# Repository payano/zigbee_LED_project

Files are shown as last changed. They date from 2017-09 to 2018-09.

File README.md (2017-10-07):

# zigbee_LED_project

Inspiration:
https://arduinodiy.wordpress.com/2012/05/02/using-mosfets-with-ttl-levels/

this aswell: https://github.com/karlp/Mrf24j40-arduino-library/

Potentiometer
BC547
IRF3205
LED-panel (aliexpress)
RGBW-led strips (aliexpress)

THIS TOO: https://electronics.stackexchange.com/questions/132000/stm32-series-microcontroller-calculations-of-timer-variables

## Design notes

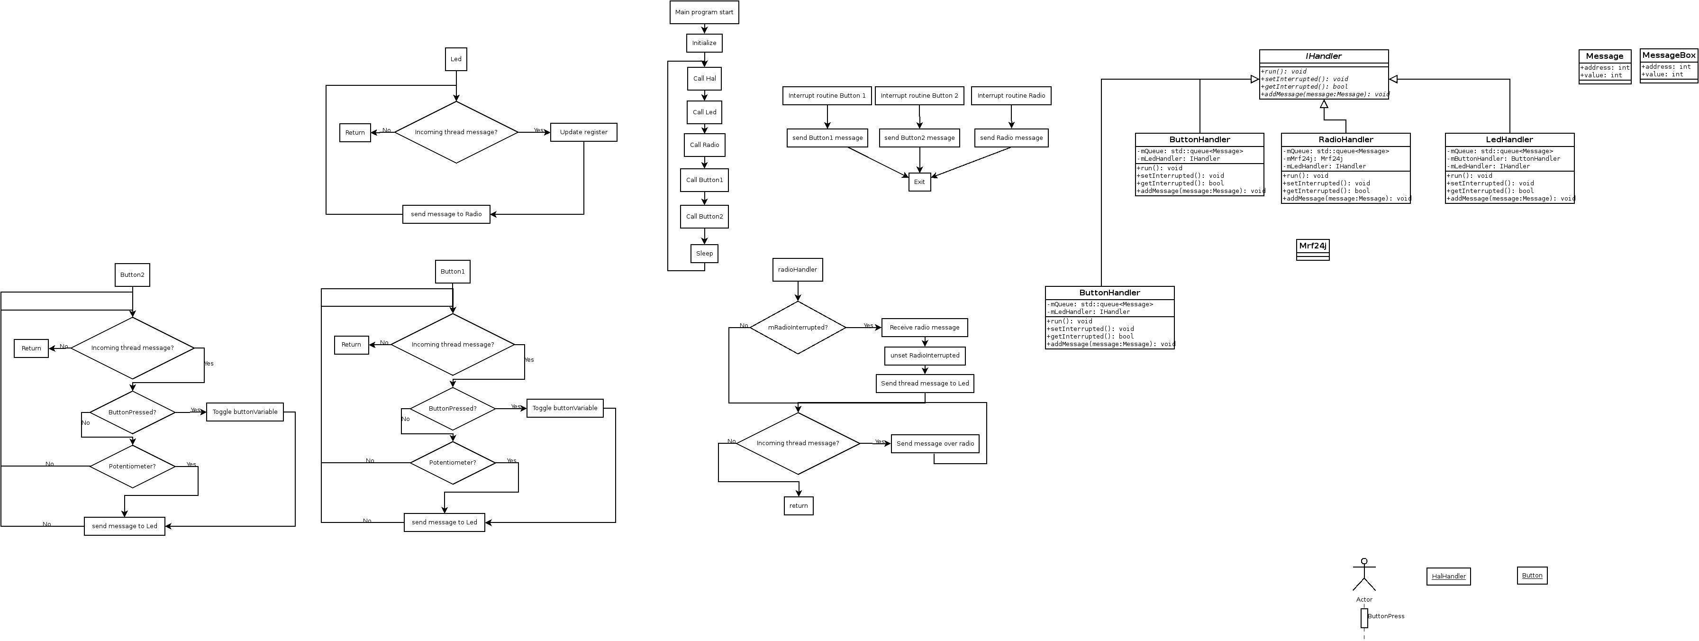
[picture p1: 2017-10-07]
flowchart.png

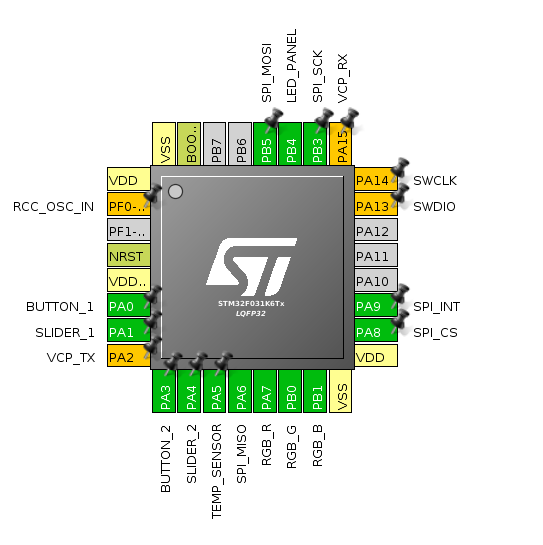
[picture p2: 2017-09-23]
stm32_layout.png

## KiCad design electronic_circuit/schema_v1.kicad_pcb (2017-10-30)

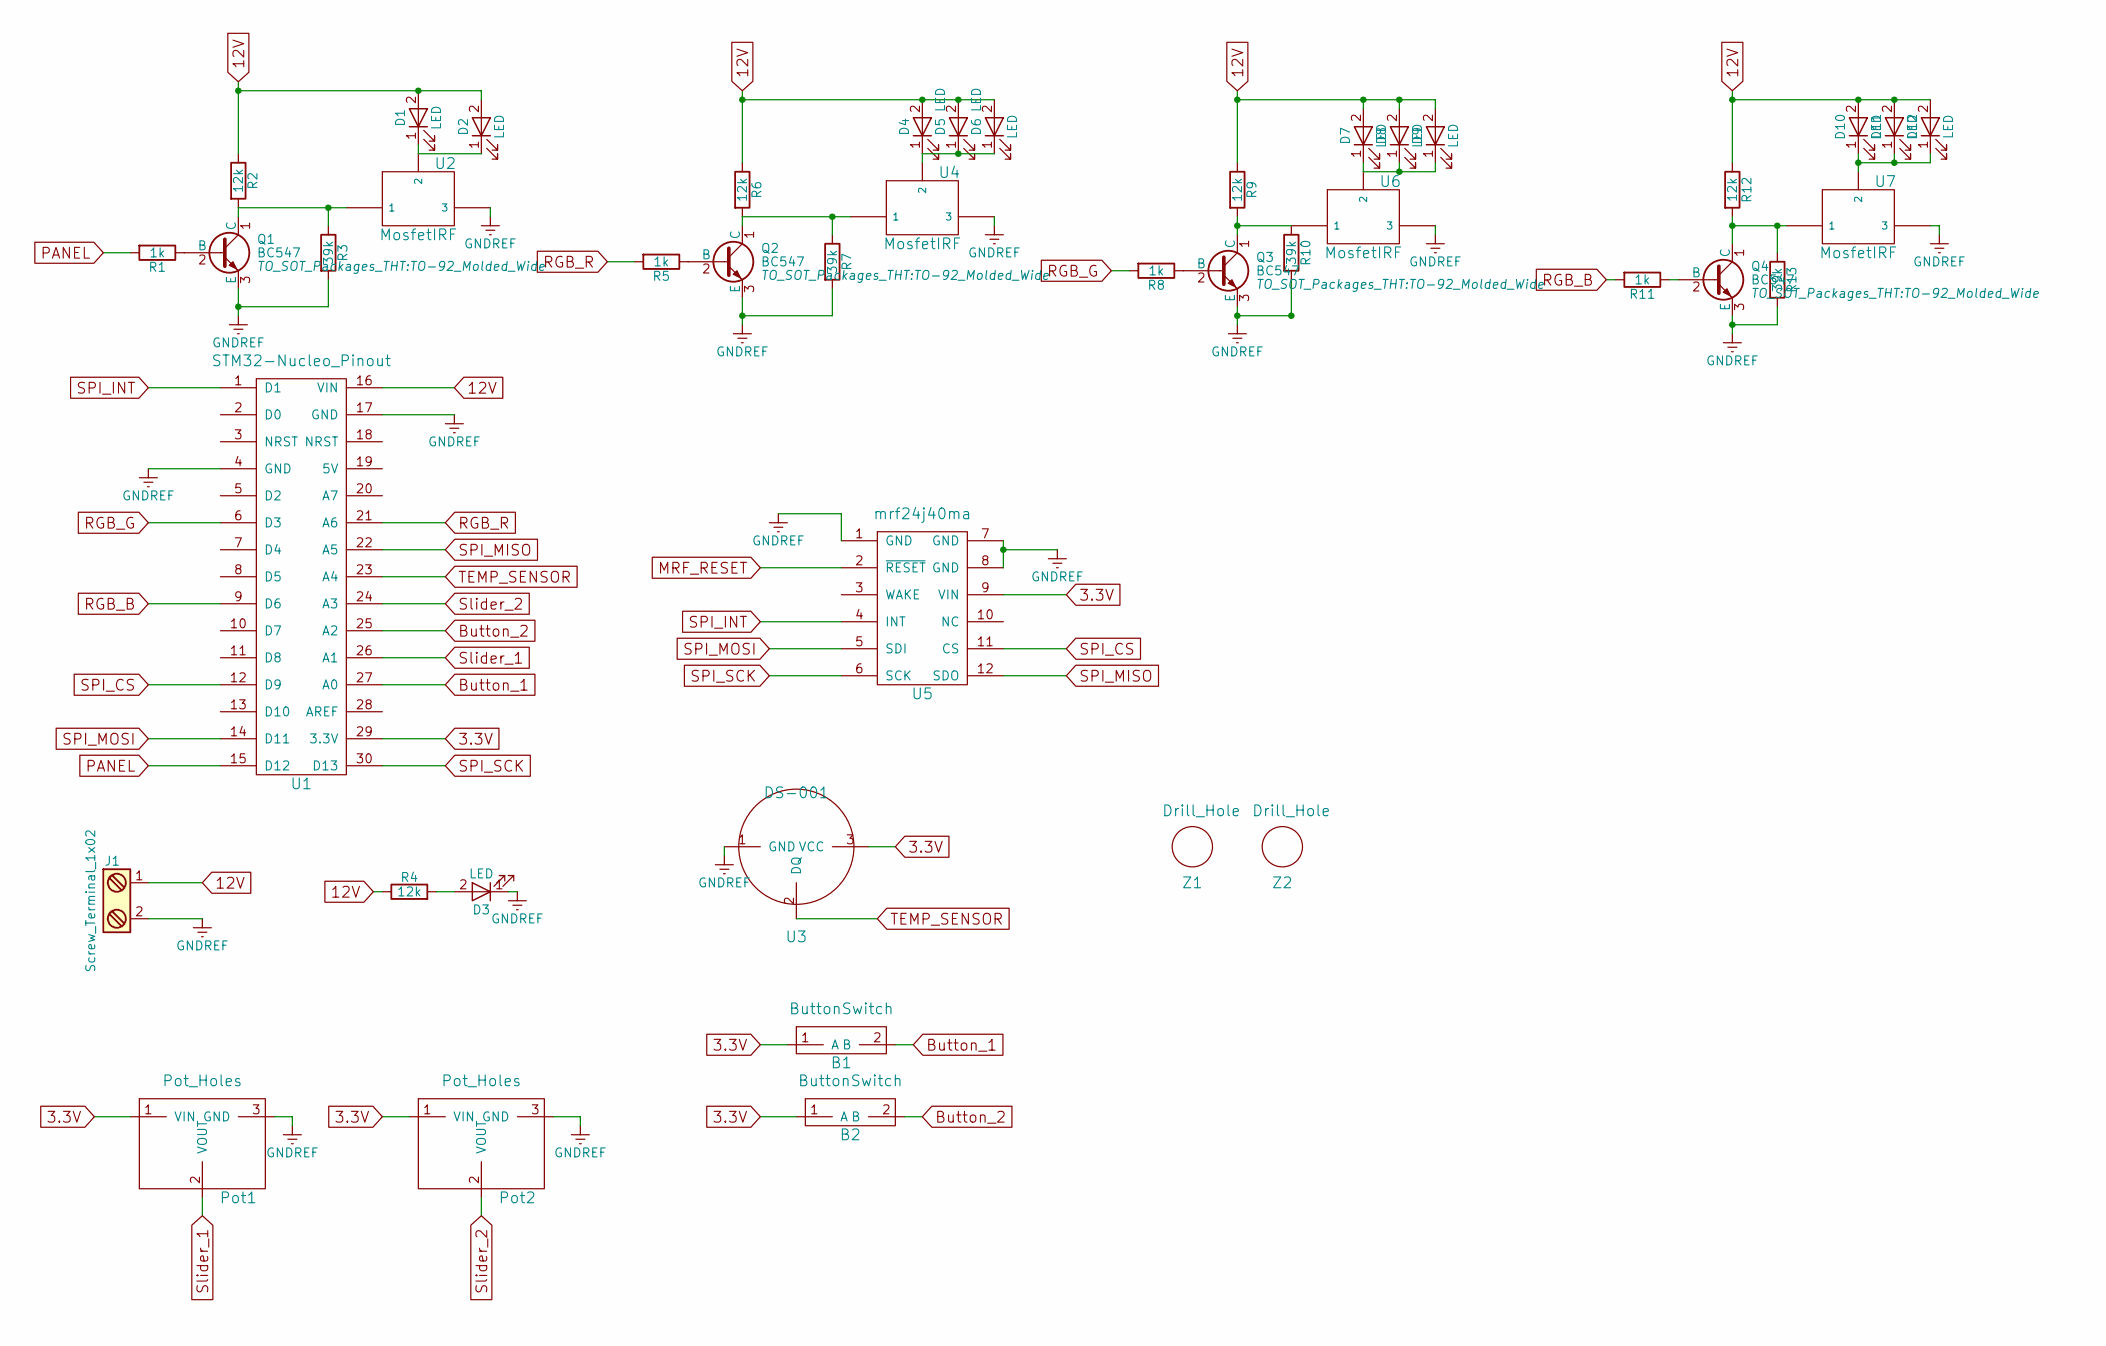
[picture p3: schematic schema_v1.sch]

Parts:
B1, B2: ButtonSwitch
D1, D2, D3, D4, D5, D6, D7, D8, D9, D10, D11, D12: LED; LED-8MM
J1: Screw_Terminal_1x02; P_Led_Holes
Pot1, Pot2: Pot_Holes
Q1, Q2, Q3, Q4: BC547; TO-92_Molded_Wide
R1, R5, R8, R11: 1k; R_1206
R2, R4, R6, R9, R12: 12k; R_1206
R3, R7, R10, R13: 39k; R_1206
U1: STM32-Nucleo_Pinout
U2, U4, U6, U7: MosfetIRF; IRF3205
U3: DS-001; TO-92_Molded_Wide
U5: mrf24j40ma
Z1, Z2: Drill_Hole

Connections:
3.3V: B1.1 (A), B2.1 (A), Pot1.1 (VIN), Pot2.1 (VIN), U1.29 (3.3V), U3.3 (VCC), U5.9 (VIN)
12V: D1.2 (A), D2.2 (A), D4.2 (A), D5.2 (A), D6.2 (A), D7.2 (A), D8.2 (A), D9.2 (A), D10.2 (A), D11.2 (A), D12.2 (A), J1.1, R2.1, R4.1, R6.1, R9.1, R12.1, U1.16 (VIN)
Button_1: B1.2 (B), U1.27 (A0)
Button_2: B2.2 (B), U1.25 (A2)
GNDREF: D3.1 (K), J1.2, Pot1.3 (GND), Pot2.3 (GND), Q1.3 (E), Q2.3 (E), Q3.3 (E), Q4.3 (E), R3.2, R7.2, R10.2, R13.2, U1.4 (GND), U1.17 (GND), U2.3, U3.1 (GND), U4.3, U5.1 (GND), U5.7 (GND), U5.8 (GND), U6.3, U7.3
MRF_RESET: U5.2 (~RESET)
unnamed: D1.1 (K), D2.1 (K), U2.2
unnamed: D3.2 (A), R4.2
unnamed: D4.1 (K), D5.1 (K), D6.1 (K), U4.2
unnamed: D7.1 (K), D8.1 (K), D9.1 (K), U6.2
unnamed: D10.1 (K), D11.1 (K), D12.1 (K), U7.2
unnamed: Q1.1 (C), R2.2, R3.1, U2.1
unnamed: Q1.2 (B), R1.1
unnamed: Q2.1 (C), R6.2, R7.1, U4.1
unnamed: Q2.2 (B), R5.1
unnamed: Q3.1 (C), R9.2, R10.1, U6.1
unnamed: Q3.2 (B), R8.1
unnamed: Q4.1 (C), R12.2, R13.1, U7.1
unnamed: Q4.2 (B), R11.1
PANEL: R1.2, U1.15 (D12)
RGB_B: R11.2, U1.9 (D6)
RGB_G: R8.2, U1.6 (D3)
RGB_R: R5.2, U1.21 (A6)
SPI_CS: U1.12 (D9), U5.11 (CS)
SPI_INT: U1.1 (D1), U5.4 (INT)
SPI_MISO: U1.22 (A5), U5.12 (SDO)
SPI_MOSI: U1.14 (D11), U5.5 (SDI)
SPI_SCK: U1.30 (D13), U5.6 (SCK)
Slider_1: Pot1.2 (VOUT), U1.26 (A1)
Slider_2: Pot2.2 (VOUT), U1.24 (A3)
TEMP_SENSOR: U1.23 (A4), U3.2 (DQ)

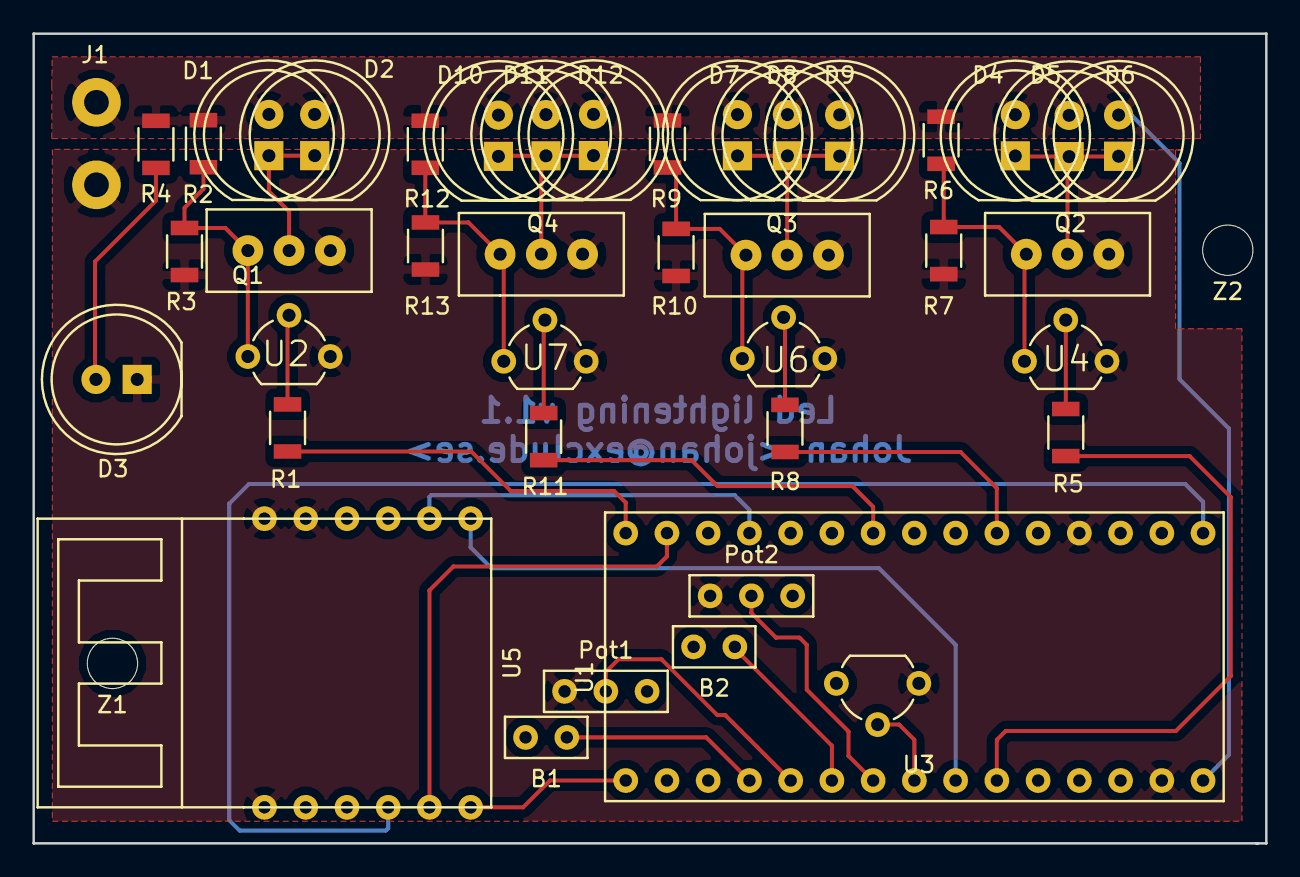
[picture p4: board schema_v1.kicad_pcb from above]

Board: 2 copper layers, 75.9 x 49.9 mm, 43 parts (0 on the bottom side), 30 nets.

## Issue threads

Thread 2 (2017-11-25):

Higher the PWM freq,.

payano, 2017-11-25:
During test with a camera the light flickers. Try to increase the frequency on the PWM to reduce the flickering.

payano, 2017-12-01:
Updated

payano, 2017-12-01:
Update on stm cubemx aswell

Closed 2017-12-20.

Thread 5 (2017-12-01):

Filter false button presses

payano, 2017-12-01:
Filter out if the interrupt got false positive.

payano, 2018-08-10:
fixed.

Closed 2018-08-10.

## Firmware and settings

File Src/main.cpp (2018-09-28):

/**
  ******************************************************************************
  * File Name          : main.c
  * Description        : Main program body
  ******************************************************************************
  ** This notice applies to any and all portions of this file
  * that are not between comment pairs USER CODE BEGIN and
  * USER CODE END. Other portions of this file, whether 
  * inserted by the user or by software development tools
  * are owned by their respective copyright owners.
  *
  * COPYRIGHT(c) 2017 STMicroelectronics
  *
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
  ******************************************************************************
  */
/* Includes ------------------------------------------------------------------*/
#include "main.h"
#include "stm32f0xx_hal.h"

#include "IHandler.h"
#include "LedHandler.h"
#include "RadioHandler.h"
#include "ButtonHandler.h"
#include "HalHandler.h"
#include "Mrf24j.h"
ADC_HandleTypeDef hadc;
DMA_HandleTypeDef hdma_adc;

SPI_HandleTypeDef hspi1;

TIM_HandleTypeDef htim3;
TIM_HandleTypeDef htim17;

constexpr int ADC_BUF_LEN = 3;
uint32_t ADC_BUF[ADC_BUF_LEN];

void SystemClock_Config(void);
static void MX_GPIO_Init(void);
static void MX_DMA_Init(void);
static void MX_SPI1_Init(void);
static void MX_TIM3_Init(void);
static void MX_ADC_Init(void);
static void MX_TIM17_Init(void);

extern "C" void HAL_TIM_MspPostInit(TIM_HandleTypeDef *htim);

Mrf24j* mrf24j;

int main(void)
{
  /* MCU Configuration----------------------------------------------------------*/

  /* Reset of all peripherals, Initializes the Flash interface and the Systick. */
  HAL_Init();


  /* Configure the system clock */
  SystemClock_Config();

  /* Initialize all configured peripherals */
  MX_GPIO_Init();
  MX_DMA_Init();
  MX_SPI1_Init();
  MX_TIM3_Init();
  MX_ADC_Init();
  MX_TIM17_Init();

  // IMPORTANT TO PLACE HANDLERS IN RIGHT ORDER,
  // CHECK IHANDLER.H
  // TODO: Removed vector and using array instead, untested!

  /**
   * make --no-print-directory post-build
    Generating binary and Printing size information:
    arm-none-eabi-objcopy -O binary "zigbee_LED_project.elf" "zigbee_LED_project.bin"
    arm-none-eabi-size "zigbee_LED_project.elf"
       text     data      bss      dec      hex  filename
      17516      144     1380    19040     4a60  zigbee_LED_project.elf
   */

  /** 2017-09-30
   * make --no-print-directory post-build
    Generating binary and Printing size information:
    arm-none-eabi-objcopy -O binary "zigbee_LED_project.elf" "zigbee_LED_project.bin"
    arm-none-eabi-size "zigbee_LED_project.elf"
       text     data      bss      dec      hex  filename
      17924      144     1380    19448     4bf8  zigbee_LED_project.elf
   */
  /** 2017-09-30
   * make --no-print-directory post-build
    Generating binary and Printing size information:
    arm-none-eabi-objcopy -O binary "zigbee_LED_project.elf" "zigbee_LED_project.bin"
    arm-none-eabi-size "zigbee_LED_project.elf"
       text     data      bss      dec      hex  filename
      18764      144     1380    20288     4f40  zigbee_LED_project.elf

      make --no-print-directory post-build
     Generating binary and Printing size information:
     arm-none-eabi-objcopy -O binary "zigbee_LED_project.elf" "zigbee_LED_project.bin"
     arm-none-eabi-size "zigbee_LED_project.elf"
        text     data      bss      dec      hex  filename
       13384      128     2244    15756     3d8c  zigbee_LED_project.elf

      2017-10-05
      make --no-print-directory post-build
      Generating binary and Printing size information:
      arm-none-eabi-objcopy -O binary "zigbee_LED_project.elf" "zigbee_LED_project.bin"
      arm-none-eabi-size "zigbee_LED_project.elf"
         text     data      bss      dec      hex  filename
        14512      128     2244    16884     41f4  zigbee_LED_project.elf
   */
  using namespace HandlerPkg;

  gpio_pin pin_reset, pin_chip_select, pin_interrupt;
  pin_chip_select.port = SPI_CS_GPIO_Port;
  pin_chip_select.pin = SPI_CS_Pin;
  pin_interrupt.port = SPI_INT_GPIO_Port;
  pin_interrupt.pin = SPI_INT_Pin;


  mrf24j = new Mrf24j(&hspi1, &pin_reset, &pin_chip_select, &pin_interrupt);

  IHandler* mHandlers[HandlerName::SIZE];

  HalHandler* Hal             = new HalHandler(HandlerName::Hal, &hadc, &htim3,&htim17, &hspi1);
  ButtonHandler* button1      = new ButtonHandler(HandlerName::Button1, Hal);
  ButtonHandler* button2      = new ButtonHandler(HandlerName::Button2, Hal);
  LedHandler* Led             = new LedHandler(HandlerName::Led, Hal);
  RadioHandler* radio         = new RadioHandler(HandlerName::Radio, Hal, mrf24j);

  //Right order is important.
  mHandlers[HandlerName::Hal] = Hal;
  mHandlers[HandlerName::Led] = Led;
  mHandlers[HandlerName::Radio] = radio;
  mHandlers[HandlerName::Button1] = button1;
  mHandlers[HandlerName::Button2] = button2;

  // Add ADC buffer to HalHandler:
  // TODO: not tested yet
  Hal->addAdcBuffer(ADC_BUF,ADC_BUF_LEN);
  // Make it possible for classes to talk to each other.
  //button reads slider and pushed button.
  mHandlers[HandlerName::Hal]->addRecipient(mHandlers[HandlerName::Button1],HandlerName::Button1);
  mHandlers[HandlerName::Hal]->addRecipient(mHandlers[HandlerName::Button2],HandlerName::Button2);
  mHandlers[HandlerName::Hal]->addRecipient(mHandlers[HandlerName::Radio],HandlerName::Radio);

  mHandlers[HandlerName::Button1]->addRecipient(mHandlers[HandlerName::Led], HandlerName::Led);
  mHandlers[HandlerName::Button1]->addRecipient(mHandlers[HandlerName::Radio], HandlerName::Radio);

  mHandlers[HandlerName::Button2]->addRecipient(mHandlers[HandlerName::Led], HandlerName::Led);
  mHandlers[HandlerName::Button2]->addRecipient(mHandlers[HandlerName::Radio], HandlerName::Radio);

  mHandlers[HandlerName::Radio]->addRecipient(mHandlers[HandlerName::Led], HandlerName::Led);
  mHandlers[HandlerName::Radio]->addRecipient(mHandlers[HandlerName::Button1], HandlerName::Button1);
  mHandlers[HandlerName::Radio]->addRecipient(mHandlers[HandlerName::Button2], HandlerName::Button2);


  mHandlers[HandlerName::Led]->addRecipient(mHandlers[HandlerName::Radio], HandlerName::Radio);

  // Enable interrupt:
  /* EXTI interrupt init*/
  HAL_NVIC_EnableIRQ(EXTI0_1_IRQn);
  HAL_NVIC_EnableIRQ(EXTI2_3_IRQn);
  HAL_NVIC_EnableIRQ(EXTI4_15_IRQn);

  // Start pwm:
  HAL_TIM_PWM_Start_IT(&htim3, TIM_CHANNEL_1);
  HAL_TIM_PWM_Start_IT(&htim3, TIM_CHANNEL_2);
  HAL_TIM_PWM_Start_IT(&htim3, TIM_CHANNEL_3);
  HAL_TIM_PWM_Start_IT(&htim3, TIM_CHANNEL_4);

  // Init all objects.
  for(IHandler* item : mHandlers){
    item->init();
  }

  // Start ADC:
  // ADC will go to a callback method: void HAL_ADC_ConvCpltCallback(ADC_HandleTypeDef* hadc)
  HAL_ADC_Start_DMA(&hadc, (uint32_t*)ADC_BUF,2);

  while (1)
  {

     for(IHandler* item : mHandlers){
        item->run();
     }
 	HAL_Delay(10);
  }

}

void HAL_ADC_ConvCpltCallback(ADC_HandleTypeDef* hadc){
    using namespace HandlerPkg;
    HalHandler::setInterrupted(HandlerName::Hal);
}

void HAL_GPIO_EXTI_Callback(uint16_t GPIO_Pin){
  if(GPIO_Pin == SPI_INT_Pin){
    mrf24j->interrupt_handler();
  }
}

/** System Clock Configuration
*/
void SystemClock_Config(void)
{

  RCC_OscInitTypeDef RCC_OscInitStruct;
  RCC_ClkInitTypeDef RCC_ClkInitStruct;

    /**Initializes the CPU, AHB and APB busses clocks 
    */
  RCC_OscInitStruct.OscillatorType = RCC_OSCILLATORTYPE_HSI|RCC_OSCILLATORTYPE_HSI14;
  RCC_OscInitStruct.HSIState = RCC_HSI_ON;
  RCC_OscInitStruct.HSI14State = RCC_HSI14_ON;
  RCC_OscInitStruct.HSICalibrationValue = 16;
  RCC_OscInitStruct.HSI14CalibrationValue = 16;
  RCC_OscInitStruct.PLL.PLLState = RCC_PLL_ON;
  RCC_OscInitStruct.PLL.PLLSource = RCC_PLLSOURCE_HSI;
  RCC_OscInitStruct.PLL.PLLMUL = RCC_PLL_MUL12;
  RCC_OscInitStruct.PLL.PREDIV = RCC_PREDIV_DIV1;
  if (HAL_RCC_OscConfig(&RCC_OscInitStruct) != HAL_OK)
  {
    _Error_Handler(__FILE__, __LINE__);
  }

    /**Initializes the CPU, AHB and APB busses clocks 
    */
  RCC_ClkInitStruct.ClockType = RCC_CLOCKTYPE_HCLK|RCC_CLOCKTYPE_SYSCLK
                              |RCC_CLOCKTYPE_PCLK1;
  RCC_ClkInitStruct.SYSCLKSource = RCC_SYSCLKSOURCE_PLLCLK;
  RCC_ClkInitStruct.AHBCLKDivider = RCC_SYSCLK_DIV1;
  RCC_ClkInitStruct.APB1CLKDivider = RCC_HCLK_DIV1;

  if (HAL_RCC_ClockConfig(&RCC_ClkInitStruct, FLASH_LATENCY_1) != HAL_OK)
  {
    _Error_Handler(__FILE__, __LINE__);
  }

    /**Configure the Systick interrupt time 
    */
  HAL_SYSTICK_Config(HAL_RCC_GetHCLKFreq()/1000);

    /**Configure the Systick 
    */
  HAL_SYSTICK_CLKSourceConfig(SYSTICK_CLKSOURCE_HCLK);

  /* SysTick_IRQn interrupt configuration */
  HAL_NVIC_SetPriority(SysTick_IRQn, 0, 0);
}

/* ADC init function */
static void MX_ADC_Init(void)
{

  ADC_ChannelConfTypeDef sConfig;

    /**Configure the global features of the ADC (Clock, Resolution, Data Alignment and number of conversion)
    */
  hadc.Instance = ADC1;
  hadc.Init.ClockPrescaler = ADC_CLOCK_ASYNC_DIV1;
  hadc.Init.Resolution = ADC_RESOLUTION_12B;
  hadc.Init.DataAlign = ADC_DATAALIGN_RIGHT;
  hadc.Init.ScanConvMode = ADC_SCAN_DIRECTION_FORWARD;
  hadc.Init.EOCSelection = ADC_EOC_SINGLE_CONV;
  hadc.Init.LowPowerAutoWait = DISABLE;
  hadc.Init.LowPowerAutoPowerOff = DISABLE;
  hadc.Init.ContinuousConvMode = DISABLE;
  hadc.Init.DiscontinuousConvMode = DISABLE;
  hadc.Init.ExternalTrigConv = ADC_SOFTWARE_START;
  hadc.Init.ExternalTrigConvEdge = ADC_EXTERNALTRIGCONVEDGE_NONE;
  hadc.Init.DMAContinuousRequests = DISABLE;
  hadc.Init.Overrun = ADC_OVR_DATA_PRESERVED;
  if (HAL_ADC_Init(&hadc) != HAL_OK)
  {
    _Error_Handler(__FILE__, __LINE__);
  }

    /**Configure for the selected ADC regular channel to be converted.
    */
  sConfig.Channel = ADC_CHANNEL_1;
  sConfig.Rank = ADC_RANK_CHANNEL_NUMBER;
  sConfig.SamplingTime = ADC_SAMPLETIME_7CYCLES_5;
  if (HAL_ADC_ConfigChannel(&hadc, &sConfig) != HAL_OK)
  {
    _Error_Handler(__FILE__, __LINE__);
  }

    /**Configure for the selected ADC regular channel to be converted.
    */
  sConfig.Channel = ADC_CHANNEL_4;
  if (HAL_ADC_ConfigChannel(&hadc, &sConfig) != HAL_OK)
  {
    _Error_Handler(__FILE__, __LINE__);
  }

    /**Configure for the selected ADC regular channel to be converted.
    */
  sConfig.Channel = ADC_CHANNEL_5;
  if (HAL_ADC_ConfigChannel(&hadc, &sConfig) != HAL_OK)
  {
    _Error_Handler(__FILE__, __LINE__);
  }

}

/* SPI1 init function */
static void MX_SPI1_Init(void)
{

  hspi1.Instance = SPI1;
  hspi1.Init.Mode = SPI_MODE_MASTER;
  hspi1.Init.Direction = SPI_DIRECTION_2LINES;
  hspi1.Init.DataSize = SPI_DATASIZE_8BIT;
  hspi1.Init.CLKPolarity = SPI_POLARITY_LOW;
  hspi1.Init.CLKPhase = SPI_PHASE_1EDGE;
  hspi1.Init.NSS = SPI_NSS_SOFT;
  hspi1.Init.BaudRatePrescaler = SPI_BAUDRATEPRESCALER_16;
  hspi1.Init.FirstBit = SPI_FIRSTBIT_MSB;
  hspi1.Init.TIMode = SPI_TIMODE_DISABLE;
  hspi1.Init.CRCCalculation = SPI_CRCCALCULATION_DISABLE;
  hspi1.Init.CRCPolynomial = 7;
  hspi1.Init.CRCLength = SPI_CRC_LENGTH_DATASIZE;
  hspi1.Init.NSSPMode = SPI_NSS_PULSE_ENABLE;
  if (HAL_SPI_Init(&hspi1) != HAL_OK)
  {
    _Error_Handler(__FILE__, __LINE__);
  }

}

/* TIM3 init function */
static void MX_TIM3_Init(void)
{

  TIM_ClockConfigTypeDef sClockSourceConfig;
  TIM_MasterConfigTypeDef sMasterConfig;
  TIM_OC_InitTypeDef sConfigOC;

  htim3.Instance = TIM3;
  htim3.Init.Prescaler = 19;
  htim3.Init.CounterMode = TIM_COUNTERMODE_UP;
  htim3.Init.Period = 254;
  htim3.Init.ClockDivision = TIM_CLOCKDIVISION_DIV4;
  htim3.Init.AutoReloadPreload = TIM_AUTORELOAD_PRELOAD_ENABLE;
  if (HAL_TIM_Base_Init(&htim3) != HAL_OK)
  {
    _Error_Handler(__FILE__, __LINE__);
  }

  sClockSourceConfig.ClockSource = TIM_CLOCKSOURCE_INTERNAL;
  if (HAL_TIM_ConfigClockSource(&htim3, &sClockSourceConfig) != HAL_OK)
  {
    _Error_Handler(__FILE__, __LINE__);
  }

  if (HAL_TIM_PWM_Init(&htim3) != HAL_OK)
  {
    _Error_Handler(__FILE__, __LINE__);
  }

  sMasterConfig.MasterOutputTrigger = TIM_TRGO_RESET;
  sMasterConfig.MasterSlaveMode = TIM_MASTERSLAVEMODE_DISABLE;
  if (HAL_TIMEx_MasterConfigSynchronization(&htim3, &sMasterConfig) != HAL_OK)
  {
    _Error_Handler(__FILE__, __LINE__);
  }

  sConfigOC.OCMode = TIM_OCMODE_PWM1;
  sConfigOC.Pulse = 254;
  sConfigOC.OCPolarity = TIM_OCPOLARITY_HIGH;
  sConfigOC.OCFastMode = TIM_OCFAST_DISABLE;
  if (HAL_TIM_PWM_ConfigChannel(&htim3, &sConfigOC, TIM_CHANNEL_1) != HAL_OK)
  {
    _Error_Handler(__FILE__, __LINE__);
  }

  if (HAL_TIM_PWM_ConfigChannel(&htim3, &sConfigOC, TIM_CHANNEL_2) != HAL_OK)
  {
    _Error_Handler(__FILE__, __LINE__);
  }

  if (HAL_TIM_PWM_ConfigChannel(&htim3, &sConfigOC, TIM_CHANNEL_3) != HAL_OK)
  {
    _Error_Handler(__FILE__, __LINE__);
  }

  if (HAL_TIM_PWM_ConfigChannel(&htim3, &sConfigOC, TIM_CHANNEL_4) != HAL_OK)
  {
    _Error_Handler(__FILE__, __LINE__);
  }

  HAL_TIM_MspPostInit(&htim3);

}

/* TIM17 init function */
static void MX_TIM17_Init(void)
{

  htim17.Instance = TIM17;
  htim17.Init.Prescaler = 100;
  htim17.Init.CounterMode = TIM_COUNTERMODE_UP;
  htim17.Init.Period = 100;
  htim17.Init.ClockDivision = TIM_CLOCKDIVISION_DIV1;
  htim17.Init.RepetitionCounter = 0;
  htim17.Init.AutoReloadPreload = TIM_AUTORELOAD_PRELOAD_DISABLE;
  if (HAL_TIM_Base_Init(&htim17) != HAL_OK)
  {
    while(1){;}
//    _Error_Handler(__FILE__, __LINE__);
  }

}
/**
  * Enable DMA controller clock
  */
static void MX_DMA_Init(void)
{
  /* DMA controller clock enable */
  __HAL_RCC_DMA1_CLK_ENABLE();

  /* DMA interrupt init */
  /* DMA1_Channel1_IRQn interrupt configuration */
  HAL_NVIC_SetPriority(DMA1_Channel1_IRQn, 0, 0);
  HAL_NVIC_EnableIRQ(DMA1_Channel1_IRQn);

}

/** Configure pins as 
        * Analog 
        * Input 
        * Output
        * EVENT_OUT
        * EXTI
     PA2   ------> USART1_TX
     PA15   ------> USART1_RX
*/
static void MX_GPIO_Init(void)
{

  GPIO_InitTypeDef GPIO_InitStruct;

  /* GPIO Ports Clock Enable */
  __HAL_RCC_GPIOF_CLK_ENABLE();
  __HAL_RCC_GPIOA_CLK_ENABLE();
  __HAL_RCC_GPIOB_CLK_ENABLE();

  /*Configure GPIO pin Output Level */
  HAL_GPIO_WritePin(SPI_CS_GPIO_Port, SPI_CS_Pin, GPIO_PIN_RESET);

  /*Configure GPIO pin Output Level */
  HAL_GPIO_WritePin(GPIOB, MRF_RESET_Pin|MRF_WAKE_Pin, GPIO_PIN_RESET);

  /*Configure GPIO pins : BUTTON_1_Pin BUTTON_2_Pin */
  GPIO_InitStruct.Pin = BUTTON_1_Pin|BUTTON_2_Pin;
  GPIO_InitStruct.Mode = GPIO_MODE_IT_RISING;
  GPIO_InitStruct.Pull = GPIO_PULLDOWN;
  HAL_GPIO_Init(GPIOA, &GPIO_InitStruct);

  /*Configure GPIO pins : VCP_TX_Pin VCP_RX_Pin */
  GPIO_InitStruct.Pin = VCP_TX_Pin|VCP_RX_Pin;
  GPIO_InitStruct.Mode = GPIO_MODE_AF_PP;
  GPIO_InitStruct.Pull = GPIO_NOPULL;
  GPIO_InitStruct.Speed = GPIO_SPEED_FREQ_HIGH;
  GPIO_InitStruct.Alternate = GPIO_AF1_USART1;
  HAL_GPIO_Init(GPIOA, &GPIO_InitStruct);

  /*Configure GPIO pin : SPI_CS_Pin */
  GPIO_InitStruct.Pin = SPI_CS_Pin;
  GPIO_InitStruct.Mode = GPIO_MODE_OUTPUT_PP;
  GPIO_InitStruct.Pull = GPIO_PULLUP;
  GPIO_InitStruct.Speed = GPIO_SPEED_FREQ_MEDIUM;
  HAL_GPIO_Init(SPI_CS_GPIO_Port, &GPIO_InitStruct);

  /*Configure GPIO pin : SPI_INT_Pin */
  GPIO_InitStruct.Pin = SPI_INT_Pin;
  GPIO_InitStruct.Mode = GPIO_MODE_IT_FALLING;
  GPIO_InitStruct.Pull = GPIO_NOPULL;
  HAL_GPIO_Init(SPI_INT_GPIO_Port, &GPIO_InitStruct);

  /*Configure GPIO pin : MRF_RESET_Pin */
  GPIO_InitStruct.Pin = MRF_RESET_Pin;
  GPIO_InitStruct.Mode = GPIO_MODE_OUTPUT_PP;
  GPIO_InitStruct.Pull = GPIO_NOPULL;
  GPIO_InitStruct.Speed = GPIO_SPEED_FREQ_MEDIUM;
  HAL_GPIO_Init(MRF_RESET_GPIO_Port, &GPIO_InitStruct);

  /*Configure GPIO pin : MRF_WAKE_Pin */
  GPIO_InitStruct.Pin = MRF_WAKE_Pin;
  GPIO_InitStruct.Mode = GPIO_MODE_OUTPUT_PP;
  GPIO_InitStruct.Pull = GPIO_NOPULL;
  GPIO_InitStruct.Speed = GPIO_SPEED_FREQ_LOW;
  HAL_GPIO_Init(MRF_WAKE_GPIO_Port, &GPIO_InitStruct);

  /* EXTI interrupt init*/
  HAL_NVIC_SetPriority(EXTI0_1_IRQn, 0, 0);
  HAL_NVIC_EnableIRQ(EXTI0_1_IRQn);

  HAL_NVIC_SetPriority(EXTI2_3_IRQn, 0, 0);
  HAL_NVIC_EnableIRQ(EXTI2_3_IRQn);

  HAL_NVIC_SetPriority(EXTI4_15_IRQn, 0, 0);
  HAL_NVIC_EnableIRQ(EXTI4_15_IRQn);

}

/**
  * @brief  Period elapsed callback in non blocking mode
  * @note   This function is called  when TIM14 interrupt took place, inside
  * HAL_TIM_IRQHandler(). It makes a direct call to HAL_IncTick() to increment
  * a global variable "uwTick" used as application time base.
  * @param  htim : TIM handle
  * @retval None
  */
void HAL_TIM_PeriodElapsedCallback(TIM_HandleTypeDef *htim)
{
  if (htim->Instance == TIM14) {
    HAL_IncTick();
  }
}

/**
  * @brief  This function is executed in case of error occurrence.
  * @param  None
  * @retval None
  */
void _Error_Handler(char * file, int line)
{
  /* USER CODE BEGIN Error_Handler_Debug */
  /* User can add his own implementation to report the HAL error return state */
  while(1) 
  {
  }
  /* USER CODE END Error_Handler_Debug */
}

#ifdef USE_FULL_ASSERT

/**
   * @brief Reports the name of the source file and the source line number
   * where the assert_param error has occurred.
   * @param file: pointer to the source file name
   * @param line: assert_param error line source number
   * @retval None
   */
void assert_failed(uint8_t* file, uint32_t line)
{
  /* USER CODE BEGIN 6 */
  /* User can add his own implementation to report the file name and line number,
    ex: printf("Wrong parameters value: file %s on line %d\r\n", file, line) */
  /* USER CODE END 6 */

}

#endif

/**
  * @}
  */ 

/**
  * @}
*/ 

/************************ (C) COPYRIGHT STMicroelectronics *****END OF FILE****/

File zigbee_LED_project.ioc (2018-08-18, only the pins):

Mcu.UserName=STM32F031K6Tx
PA0.GPIO_Label=BUTTON_1
PA0.Signal=GPXTI0
PA1.GPIO_Label=SLIDER_1
PA1.Signal=ADC_IN1
PA13.GPIO_Label=SWDIO
PA13.Signal=SYS_SWDIO
PA14.GPIO_Label=SWCLK
PA14.Signal=SYS_SWCLK
PA15.GPIO_Label=VCP_RX
PA15.Signal=USART1_RX
PA2.GPIO_Label=VCP_TX
PA2.Signal=USART1_TX
PA3.GPIO_Label=BUTTON_2
PA3.Signal=GPXTI3
PA4.GPIO_Label=SLIDER_2
PA4.Signal=ADC_IN4
PA5.GPIO_Label=TEMP_SENSOR
PA5.Signal=ADC_IN5
PA6.GPIO_Label=SPI_MISO
PA6.Signal=SPI1_MISO
PA7.GPIO_Label=LED_PANEL
PA7.Signal=S_TIM3_CH2
PA8.GPIO_Label=SPI_CS
PA8.Signal=GPIO_Output
PA9.GPIO_Label=SPI_INT
PA9.Signal=GPXTI9
PB0.GPIO_Label=RGB_R
PB0.Signal=S_TIM3_CH3
PB1.GPIO_Label=RGB_G
PB1.Signal=S_TIM3_CH4
PB3.GPIO_Label=SPI_SCK
PB3.Signal=SPI1_SCK
PB4.GPIO_Label=RGB_B
PB4.Signal=S_TIM3_CH1
PB5.GPIO_Label=SPI_MOSI
PB5.Signal=SPI1_MOSI
PB6.GPIO_Label=MRF_RESET
PB6.Signal=GPIO_Output
PB7.GPIO_Label=MRF_WAKE
PB7.Signal=GPIO_Output
PF0-OSC_IN.Signal=RCC_OSC_IN

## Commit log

2017-09-19 updated flowchart
2017-09-21 removed FreeRTOS due to hardware limitations, Changed flowchart and class schema. Refactored code to not use FreeRTOS.
2017-09-21 added eclipse warnings to errors! Updated flowchart
    [Mrf24j.cpp, main.cpp, main.h]
2017-09-22 successfully send message between classes.
    [zigbee_LED_project Debug.cfg]
2017-09-22 interrupts working.
2017-09-23 fixed ADC DMA and button interrupts
    [main.cpp, zigbee_LED_project.ioc]
2017-09-25 added a interrupthandler, also refactored some.
2017-09-26 Renamed InterruptHandler to HalHandler, and also did some refactoring.
2017-09-30 HalHandler and LedHandler has a working concept.
2017-09-30 Buttonhandler is tricky.
2017-10-03 Got stuck in a infinite loop, when std::queue got removed it worked better.
    [main.cpp, zigbee_LED_project.ioc]
2017-10-06 buttons and led almost done.
2017-10-07 Working prototype.
2017-10-07 Reworked flowchart.
2017-10-07 timer calc
2017-10-15 Added pull up on PWM.
2017-10-15 Added pulldown on buttons
2017-10-18 A layout circuit diagram made in kicad.
    [schema_v1-B.Cu.gbr, schema_v1-B.Mask.gbr, schema_v1-B.SilkS.gbr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]
2017-10-30 New electronic schema
    [schema_v1-B.Cu.gbr, schema_v1-B.Mask.gbr, schema_v1-B.SilkS.gbr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]
2017-10-31 mapped channels to right output on the PCB.
2017-11-04 changed bouncing on button and that the pot could not set the brightness to 0 (254).
2017-12-01 Issue 1: Remapped Pot1 -> B1 and Pot2 > B2
    [HalHandler.cpp]
2017-12-01 Issue 2: PWM changed to 10Khz.
    [main.cpp]
2017-12-02 Issue 6: Lowered PWM output speed, Issue 2: Also made changes to STM32CubeMX
    [main.cpp, zigbee_LED_project.ioc]
2017-12-04 Issue 2: PWM speed is now 31khz
    [main.cpp, zigbee_LED_project.ioc]
2017-12-04 Issue 4: Created a start issue for all classes
    [HalHandler.cpp]
2017-12-06 Issue 5: Added a filter that removes the first interrupt
2017-12-06 Issue 5: Also made sure that the filter only applies on HAL messages.
2017-12-20 Issue 5: A new implementation of the bouncing problem.
    [HalHandler.cpp]
2017-12-20 Lowered pwm to 10khz.
2018-07-23 working prototype with rgb
2018-07-24 more work on radio, button bouncing is fixed.
    [HalHandler.cpp, main.cpp]
2018-09-25 Now enables the interrupt at the last row in the interrupt routine.
2018-09-28 Revert "Now enables the interrupt at the last row in the interrupt routine."
    This reverts commit 2f00c25a86d0ec09e644e9e87e42694efe517a78.
    [HalHandler.cpp, main.cpp]
2018-09-28 shortened the delay of the main loop
    [main.cpp]
